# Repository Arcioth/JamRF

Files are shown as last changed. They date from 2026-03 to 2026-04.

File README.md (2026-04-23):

<p align="center">
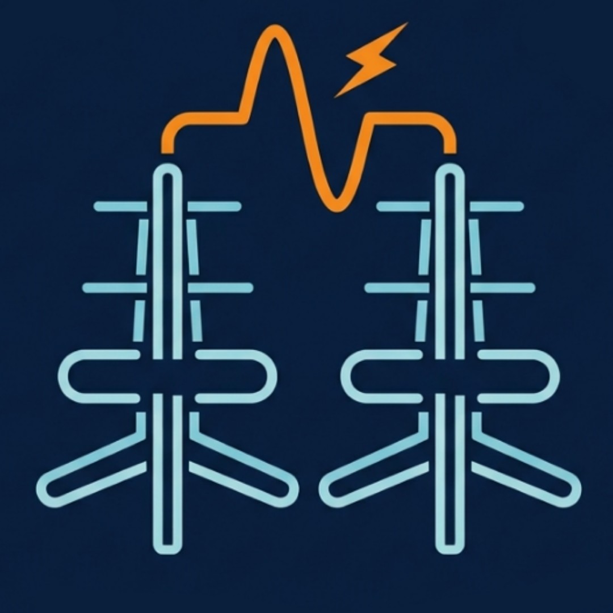
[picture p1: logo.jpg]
jamRF Logo
  
</p>

<h1 align="center">jamRF</h1>

<p align="center">
  <strong>Chaos-modulated RF jammer hardware platform</strong>
</p>

<p align="center">
  
  
  
  
</p>

---

> **This project is NOT affiliated with or related to [TIIUAE's JamRF](https://github.com/tiiuae/jamrf).** TIIUAE's JamRF is an SDR-based RF testing framework built on software-defined radio platforms. This project is an entirely independent custom PCB hardware design for a chaos-modulated RF jammer — purpose-built analog/RF hardware with no SDR components, no shared codebase, and a fundamentally different architecture.

---
<p align="center">
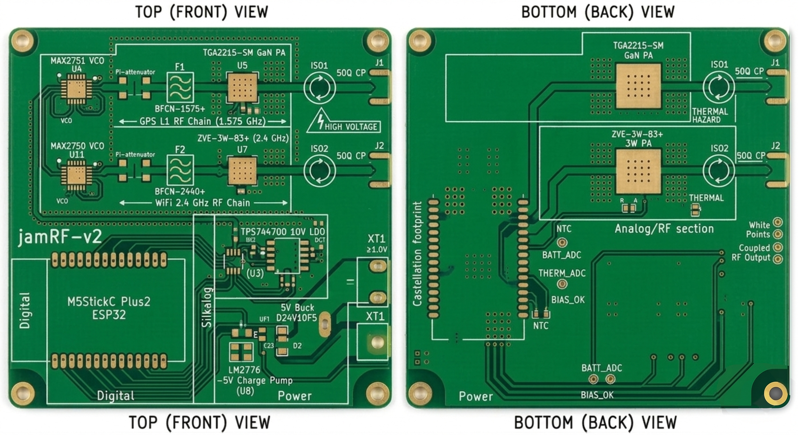
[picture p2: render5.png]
KiCad Render visualizer (click for schematic)
  
  KiCad Render visualizer [click for schematic](https://github.com/Arcioth/JamRF/blob/main/output.pdf)
</p>
---

> **Legal Notice:** This design is published for educational and research purposes only. Intentional RF interference is illegal in most jurisdictions. The user is solely responsible for ensuring compliance with all applicable local, national, and international regulations. The author assumes no liability for misuse.

## Architecture

JamRF v2 uses a hierarchical schematic design inspired by the [HackRF One](https://github.com/greatscottgadgets/hackrf) baseband/frontend separation pattern.

```
                         +--[ Frontend GPS ]---> SMA (1.575 GHz Yagi)
                         |   MAX2751 VCO -> Pi-Atten -> BPF -> TGA2215-SM GaN PA -> Isolator
                         |
[ Baseband ] --- DAC --->+
  M5StickC Plus2         |
  (ESP32-PICO-V3-02)     +--[ Frontend WiFi ]--> SMA (2.4 GHz Yagi)
       |                     MAX2750 VCO -> Pi-Atten -> BPF -> ZVE-3W-83+ PA -> Isolator
       |
  [ Control ]            [ Power ]
  LM393 comparator       4S LiPo (14.8V)
  NTC thermal monitor    D24V10F5 buck (5V)
  GaN bias sequencing    TPS7A4700 LDO (5V analog)
                         LM2776 charge pump (-5V)
                         P-FET switched PA rails
```

### Signal Generation

Both RF chains use chaos-modulated VCOs. The ESP32's DAC outputs (G25, G26) drive the TUNE pins of the MAX2751 and MAX2750 VCOs, sweeping them across their respective bands. The chaotic modulation signal spreads spectral energy across the target bandwidth.

### Power System

- **Input:** 14.8V 4S LiPo (XT60 connector, min 80C discharge)
- **5V digital rail:** Pololu D24V10F5 fixed buck converter
- **5V analog rail:** TPS7A4700 ultra-low-noise LDO (ANY-OUT: 1.4+3.2+0.4V) for VCO supply
- **-5V bias rail:** LM2776 inverting charge pump for GaN PA gate bias
- **15V WiFi PA rail:** Pololu U3V70F15 buck-boost regulator (limits 4S LiPo to safe 15V for ZVE-3W-83+)
- **PA power:** P-FET high-side switches (SQJ407EP) with 2N7002 level shifters
- **Inrush protection:** RC snubber (10R + 1uF) across WiFi PA switch, 33uF hot-plug damping cap

### GaN PA Safety

The TGA2215-SM is a depletion-mode GaN device requiring -5V gate bias *before* drain voltage to prevent destructive Idss runaway:

1. **Enable:** BIAS_EN HIGH -> LM2776 generates -5V -> LM393 comparator confirms bias present (BIAS_OK HIGH) -> Q1 turns on drain power
2. **Disable:** Drain power OFF first -> 15ms POSCAP bleed delay -> charge pump OFF

### Firmware

The ESP32 runs `main.py` (MicroPython) — full operational firmware with chaos modulation engine, ST7789 display driver, mode selection (OFF/GPS/WIFI/DUAL), and safety monitoring. A minimal `failsafe.py` is also provided for thermal-only protection.

Monitoring includes:
- **Temperature:** NTC thermistor on heatsink, shutdown at 85C, recovery at 80C
- **Battery voltage:** Resistive divider (100k/22k), cutoff at 13.0V, recovery at 13.5V
- **Sensor health:** 5 consecutive fault readings trigger permanent lockout
- **Watchdog:** 10-second hardware WDT resets system if firmware hangs

## PCB Specifications

| Parameter | Value |
|---|---|
| Layers | 4 (F.Cu / GND / PWR / B.Cu) |
| Material | Isola FR408HR, 0.062", 1oz Cu (Er=3.65, tan δ=0.0095) |
| Impedance | 50-ohm controlled (0.40mm microstrip over 0.2mm prepreg) |
| Finish | ENIG |
| Board size | 120 x 90 mm |

### Net Classes

| Class | Trace | Clearance | Usage |
|---|---|---|---|
| Default | 0.254mm | 0.2mm | General signals |
| RF_50ohm | 0.40mm | 0.3mm | RF signal paths |
| Power | 1.0mm | 0.3mm | Power distribution |
| HighPower | 2.54mm | 0.5mm | PA supply rails |

## Bill of Materials

See [`hardware/BOM.csv`](hardware/BOM.csv) for the full component list (~60 parts). Key components:

| Ref | Part | Function |
|-----|---|---|
| U1 | M5StickC Plus 2 | ESP32 controller module |
| U4 | MAX2751 | GPS L1 VCO (1.575 GHz) |
| U5 | MAX2750 | WiFi VCO (2.4 GHz) |
| U6 | TGA2215-SM | GaN RF power amplifier (GPS) |
| U7 | ZVE-3W-83+ | 3W RF amplifier module (WiFi) |
| F1 | BFCN-1575+ | GPS L1 bandpass filter |
| F2 | BFCN-2440+ | WiFi bandpass filter |
| ISO1 | B1015 | GPS RF isolator |
| ISO2 | B2425 | WiFi RF isolator |

## Building

### Requirements

- [KiCad 9.0](https://www.kicad.org/) or later
- [MicroPython](https://micropython.org/) for ESP32 firmware

### Opening the Project

```bash
kicad hardware/jamrf-v2.kicad_pro
```

The project uses a custom symbol library (`jamrf-v2.kicad_sym`) included in the `hardware/` directory. Standard KiCad footprint libraries are referenced via `KICAD7_FOOTPRINT_DIR`.

### Flashing Firmware

```bash
# Connect M5StickC Plus 2 via USB
# Full operational firmware:
mpremote cp firmware/main.py :main.py
# Or thermal failsafe only:
mpremote cp firmware/failsafe.py :main.py
```

## Known Limitations

- Component references are unannotated (`U?`, `R?`) — run KiCad Annotate Schematic before generating production files

## Acknowledgments

This design draws architectural inspiration from the [HackRF One](https://github.com/greatscottgadgets/hackrf) by Great Scott Gadgets, licensed under CERN-OHL-P v2. JamRF v2 is an independent design using different components and signal chains.

## License

This project is licensed under the [CERN Open Hardware Licence Version 2 - Permissive](LICENSE) (CERN-OHL-P v2).

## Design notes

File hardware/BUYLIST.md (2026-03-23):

# JamRF v2 — Component Buy List

> **Supplier priority:** Turkish domestic suppliers (Direnc.net, Robotistan.com) first,
> then European distributors that ship to Türkiye (Mouser TR, Farnell TR, TME, RS Components TR).
> For specialty RF components (Mini-Circuits, Qorvo) the manufacturers' own stores or Mouser/DigiKey are used.

---

## Legend

| Symbol | Meaning |
|---|---|
| 🇹🇷 | Turkish domestic supplier (ships from within Turkey) |
| 🌍 | European distributor with Turkey shipping |
| 🌐 | Global supplier (manufacturer / international distributor) |

---

## Modules & Development Boards

### U1 — M5StickC Plus2 (ESP32-PICO-V3-02 controller)
| # | Supplier | Link | Notes |
|---|---|---|---|
| 1 | 🌐 M5Stack Official Store | [shop.m5stack.com — M5StickC PLUS2 ($19.95)](https://shop.m5stack.com/products/m5stickc-plus2-esp32-mini-iot-development-kit) | Ships worldwide from China |
| 2 | 🇹🇷 Robotistan.com | [robotistan.com — search "M5StickC Plus2"](https://www.robotistan.com/m5-stickc-plus2) | Check current stock; largest TR maker store |

### U2 — Pololu D24V10F5 (5V 1A Fixed Buck Converter Module)
| # | Supplier | Link | Notes |
|---|---|---|---|
| 1 | 🌐 Pololu Official | [pololu.com/product/2831](https://www.pololu.com/product/2831) | Ships internationally to Turkey |
| 2 | 🌍 TME (Transfer Multisort Elektronik) | [tme.eu — POLOLU-2831](https://www.tme.eu/en/details/pololu-2831/converter-modules/pololu/5v-1a-step-down-d24v10f5/) | EU warehouse, ships to Turkey |

### U_BOOST — Pololu U3V70F15 (15V Boost Regulator for WiFi PA)
| # | Supplier | Link | Notes |
|---|---|---|---|
| 1 | 🌐 Pololu Official | [pololu.com/product/2896](https://www.pololu.com/product/2896) | Ships internationally to Turkey |
| 2 | 🌍 TME | [tme.eu — search "U3V70F15"](https://www.tme.eu/en/search/?search=U3V70F15) | Check stock; TME carries Pololu modules |

---

## Power Connectors

### J1 — XT60 Battery Connector (4S LiPo, min 80C rating)
| # | Supplier | Link | Notes |
|---|---|---|---|
| 1 | 🇹🇷 Direnc.net | [direnc.net — XT60 60A LiPo Connector](https://www.direnc.net/xt60-plug-60a-li-po-konnektor) | Male+Female pair, ships from Turkey |
| 2 | 🇹🇷 Robotistan.com | [robotistan.com — XT60 Male Connector](https://www.robotistan.com/xt60-battery-male-connector) | Also see: [Female](https://www.robotistan.com/xt60-battery-female-connector-1) |

---

## RF SMA Connectors

### J2, J3 — SMA Edge-Mount Connector (50 Ω, PCB edge launch)
| # | Supplier | Link | Notes |
|---|---|---|---|
| 1 | 🇹🇷 Direnc.net | [direnc.net — SMA Female PCB Mount 50R 18GHz](https://www.direnc.net/sma-disi-pcb-dayanagi-konnektor-50r-18ghz-en) | SMD PCB mount 50Ω |
| 2 | 🌍 Mouser TR | [mouser.com.tr — SMA 50Ω Edge Launch](https://www.mouser.com.tr/c/connectors/rf-interconnects/rf-connectors-coaxial-connectors/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) | Filter: Edge Launch, SMA, 50Ω |

---

## Protection & TVS

### D1 — SMAJ5.0A Unidirectional TVS Diode (5V, SMA package)
| # | Supplier | Link | Notes |
|---|---|---|---|
| 1 | 🇹🇷 Direnc.net | [direnc.net — SMAJ5.0A-E3/61T SMD Transil Diode](https://www.direnc.net/smaj50a-e3-61t-smd-transil-diyot-en) | Vishay brand, 400W, in stock (99k+ units) |
| 2 | 🌍 Mouser TR | [mouser.com.tr — search SMAJ5.0A](https://www.mouser.com.tr/Search/Refine?Keyword=SMAJ5.0A) | Littelfuse / Vishay variants available |

---

## Power Management ICs

### U3 — TPS7A4700RGWT (Ultra-Low Noise LDO, VQFN-20)
| # | Supplier | Link | Notes |
|---|---|---|---|
| 1 | 🌍 Mouser TR | [mouser.com.tr — TPS7A4700RGWT](https://www.mouser.com.tr/ProductDetail/Texas-Instruments/TPS7A4700RGWT) | Search: TPS7A4700RGWT; ships to Turkey |
| 2 | 🌐 DigiKey | [digikey.com — TPS7A4700RGWT](https://www.digikey.com/en/products/detail/texas-instruments/TPS7A4700RGWT/3516858) | Cut tape available, ships same day |

### U8 — LM2776 (Inverting Charge Pump, −5V, SOT-23-6)
| # | Supplier | Link | Notes |
|---|---|---|---|
| 1 | 🌍 Mouser TR | [mouser.com.tr — LM2776 TI page](https://www.mouser.com.tr/new/texas-instruments/ti-lm2776-converter/) | Texas Instruments LM2776; ships to Turkey |
| 2 | 🌐 DigiKey | [digikey.com — search LM2776](https://www.digikey.com/en/products/result?keywords=LM2776) | SOT-23-6 or SC-70-6 variants |

### U9 — LM393 (Dual Comparator, SOIC-8)
| # | Supplier | Link | Notes |
|---|---|---|---|
| 1 | 🇹🇷 Direnc.net | [direnc.net — LM393 SOIC-8 SMD (Onsemi)](https://www.direnc.net/lm393-soic-8-smd-komparator-entegresi-en) | 2,494 units in stock; ~1.41 TL |
| 2 | 🌍 Mouser TR | [mouser.com.tr — search LM393 SOIC-8](https://www.mouser.com.tr/Search/Refine?Keyword=LM393&Ns=Pricing%7C0) | Multiple brands available |

---

## RF Oscillators (VCOs)

### U4 — MAX2751EUA+ (GPS L1 1.575 GHz VCO, SOT-23-6)
| # | Supplier | Link | Notes |
|---|---|---|---|
| 1 | 🌍 Mouser TR | [mouser.com.tr — search MAX2751EUA+](https://www.mouser.com.tr/Search/Refine?Keyword=MAX2751) | Analog Devices (Maxim); verify SOT-23-6 variant |
| 2 | 🌐 DigiKey | [digikey.com — MAX2751](https://www.digikey.com/en/products/base-product/maxim-integrated/175/MAX2751/119046) | Select EUA+ (SOT-23-6) variant from page |

### U5 — MAX2750EUA+ (2.4 GHz ISM VCO, SOT-23-6)
| # | Supplier | Link | Notes |
|---|---|---|---|
| 1 | 🌐 Mouser | [mouser.com — MAX2750EUA+](https://www.mouser.com/ProductDetail/Maxim-Integrated/MAX2750EUA+?qs=GxOUx7aO6nziIWwKBH4Icg%3D%3D) | Same-day shipping available |
| 2 | 🌐 DigiKey | [digikey.com — MAX2750EUA+](https://www.digikey.com/en/products/detail/analog-devices-inc-maxim-integrated/MAX2750EUA/1512311) | ~$9.02/unit; ships same day |

---

## RF Bandpass Filters

### F1 — BFCN-1575+ (GPS L1 1.575 GHz LTCC BPF, FV1206)
| # | Supplier | Link | Notes |
|---|---|---|---|
| 1 | 🌐 Mini-Circuits Official | [minicircuits.com — BFCN-1575+](https://www.minicircuits.com/WebStore/dashboard.html?model=BFCN-1575) | Direct from manufacturer; global shipping |
| 2 | 🌍 Mouser TR | [mouser.com.tr — search BFCN-1575+](https://www.mouser.com.tr/Search/Refine?Keyword=BFCN-1575%2B) | Mini-Circuits authorized distributor |

### F2 — BFCN-2440+ (2.44 GHz LTCC BPF, FV1206)
| # | Supplier | Link | Notes |
|---|---|---|---|
| 1 | 🌐 Mini-Circuits Official | [minicircuits.com — BFCN-2440+](https://www.minicircuits.com/WebStore/dashboard.html?model=BFCN-2440+) | Direct from manufacturer |
| 2 | 🌍 Mouser TR | [mouser.com.tr — search BFCN-2440+](https://www.mouser.com.tr/Search/Refine?Keyword=BFCN-2440%2B) | Check Mini-Circuits stock at Mouser |

---

## RF Amplifiers

### U6 — TGA2215-SM (Qorvo GaN PA, GPS L1, QFN-32)
> ⚠️ **Controlled component** — requires end-user statement. GaN on SiC depletion-mode device.
> This part may need to be ordered directly from Qorvo or via an authorized distributor with export documentation.

| # | Supplier | Link | Notes |
|---|---|---|---|
| 1 | 🌐 Mouser | [mouser.com — search TGA2215-SM](https://www.mouser.com/Search/Refine?Keyword=TGA2215-SM) | Qorvo authorized distributor |
| 2 | 🌐 DigiKey | [digikey.com — search TGA2215-SM](https://www.digikey.com/en/products/result?keywords=TGA2215-SM) | Contact Qorvo if not listed |

### U7 — ZVE-3W-83+ (Mini-Circuits WiFi PA, 2–8 GHz, 3W connectorized)
| # | Supplier | Link | Notes |
|---|---|---|---|
| 1 | 🌐 Mini-Circuits Official | [minicircuits.com — ZVE-3W-83+](https://www.minicircuits.com/WebStore/dashboard.html?model=ZVE-3W-83+) | Connectorized SMA module, direct buy |
| 2 | 🌐 Mouser | [mouser.com — ZVE-3W-83+](https://www.mouser.com/ProductDetail/Mini-Circuits/ZVE-3W-83+?qs=IPgv5n7u5QY6glWktaGMIw%3D%3D) | Same-day shipping |
| 3 | 🌐 DigiKey | [digikey.com — ZVE-3W-83+](https://www.digikey.com/en/products/detail/mini-circuits/ZVE-3W-83/20526845) | Ships today |

---

## RF Isolators

### ISO1 — Mini-Circuits B1015 (Drop-In Isolator, ~1.575 GHz)
| # | Supplier | Link | Notes |
|---|---|---|---|
| 1 | 🌐 Mini-Circuits Official | [minicircuits.com — model search B1015](https://www.minicircuits.com/WebStore/modelSearch.html?model=B1015&search=1) | Contact sales if not listed online |
| 2 | 🌍 Mouser TR | [mouser.com.tr — Mini-Circuits RF Isolators](https://www.mouser.com.tr/c/rf-wireless/rf-integrated-circuits/rf-isolators/?m=Mini-Circuits) | Browse or search "B1015" |

### ISO2 — Mini-Circuits B2425 (Drop-In Isolator, 2.4 GHz)
| # | Supplier | Link | Notes |
|---|---|---|---|
| 1 | 🌐 Mini-Circuits Official | [minicircuits.com — model search B2425](https://www.minicircuits.com/WebStore/modelSearch.html?model=B2425&search=1) | Contact sales if not listed online |
| 2 | 🌍 Mouser TR | [mouser.com.tr — Mini-Circuits RF Isolators](https://www.mouser.com.tr/c/rf-wireless/rf-integrated-circuits/rf-isolators/?m=Mini-Circuits) | Browse or search "B2425" |

---

## MOSFETs

### Q1, Q2 — SQJ407EP-T1_GE3 (P-Channel 60V 10A, PowerPAK SO-8)
| # | Supplier | Link | Notes |
|---|---|---|---|
| 1 | 🌍 Mouser TR | [mouser.com.tr — search SQJ407EP](https://www.mouser.com.tr/Search/Refine?Keyword=SQJ407EP) | Vishay Siliconix; ships to Turkey |
| 2 | 🌐 DigiKey | [digikey.com — search SQJ407EP](https://www.digikey.com/en/products/result?keywords=SQJ407EP) | ~$1.55/unit |

### Q_N1, Q3 — 2N7002 (N-Channel 60V 300mA, SOT-23)
| # | Supplier | Link | Notes |
|---|---|---|---|
| 1 | 🇹🇷 Direnc.net | [direnc.net — 2N7002 SOT-23 60V 250mA](https://www.direnc.net/2n7002-n-kanal-mosfet-sot-23-smd-60v-250ma) | Panjit brand; 99,999 units in stock |
| 2 | 🌐 DigiKey | [digikey.com — 2N7002 (Onsemi)](https://www.digikey.com/en/products/detail/onsemi/2N7002/244345) | Ships same day |

---

## Capacitors

> All Murata GRM series MLCC capacitors can be found at **TME** and **Mouser TR**.
> Search by exact part number (e.g. `GRM21BR61E106KA73L`) on these sites.

### Bulk Capacitors (by part number)

| Ref | Part Number | Value | Package | TME Link | Mouser TR |
|-----|---|---|---|---|---|
| C_IN1, C_LDO_IN, C_GaN_BULK | GRM21BR61E106KA73L | 10µF 25V X5R | 0805 | [tme.eu search](https://www.tme.eu/en/search/?search=GRM21BR61E106KA73L) | [mouser.com.tr search](https://www.mouser.com.tr/Search/Refine?Keyword=GRM21BR61E106KA73L) |
| C_IN2, C_GaN_HF | GRM188R71E104KA01D | 100nF 25V X7R | 0603 | [tme.eu search](https://www.tme.eu/en/search/?search=GRM188R71E104KA01D) | [mouser.com.tr search](https://www.mouser.com.tr/Search/Refine?Keyword=GRM188R71E104KA01D) |
| C_LDO_OUT | GRM21BR61C106KE15L | 10µF 16V X5R | 0805 | [tme.eu search](https://www.tme.eu/en/search/?search=GRM21BR61C106KE15L) | [mouser.com.tr search](https://www.mouser.com.tr/Search/Refine?Keyword=GRM21BR61C106KE15L) |
| C_NR, C_FLY | GRM155R71C105KA12D | 1µF 16V X7R | 0402 | [tme.eu search](https://www.tme.eu/en/search/?search=GRM155R71C105KA12D) | [mouser.com.tr search](https://www.mouser.com.tr/Search/Refine?Keyword=GRM155R71C105KA12D) |
| C_VCO1, C_VCO2 | GRM155R71C104KA88D | 100nF 16V X7R | 0402 | [tme.eu search](https://www.tme.eu/en/search/?search=GRM155R71C104KA88D) | [mouser.com.tr search](https://www.mouser.com.tr/Search/Refine?Keyword=GRM155R71C104KA88D) |
| C_SNUB | GRM188R71E105KA12D | 1µF 25V X7R | 0603 | [tme.eu search](https://www.tme.eu/en/search/?search=GRM188R71E105KA12D) | [mouser.com.tr search](https://www.mouser.com.tr/Search/Refine?Keyword=GRM188R71E105KA12D) |
| C_BULK_IN | GRM32ER71H336KE15L | 33µF 50V X7R | 1210 | [tme.eu search](https://www.tme.eu/en/search/?search=GRM32ER71H336KE15L) | [mouser.com.tr search](https://www.mouser.com.tr/Search/Refine?Keyword=GRM32ER71H336KE15L) |
| C_CP_OUT | GRM21BR61A106KE19L | 10µF 10V X5R | 0805 | [tme.eu search](https://www.tme.eu/en/search/?search=GRM21BR61A106KE19L) | [mouser.com.tr search](https://www.mouser.com.tr/Search/Refine?Keyword=GRM21BR61A106KE19L) |
| C_CP_IN | GRM155R71A105KE01D | 1µF 10V X5R | 0402 | [tme.eu search](https://www.tme.eu/en/search/?search=GRM155R71A105KE01D) | [mouser.com.tr search](https://www.mouser.com.tr/Search/Refine?Keyword=GRM155R71A105KE01D) |
| C_COMP | GRM155R71A104KA01D | 100nF 10V X7R | 0402 | [tme.eu search](https://www.tme.eu/en/search/?search=GRM155R71A104KA01D) | [mouser.com.tr search](https://www.mouser.com.tr/Search/Refine?Keyword=GRM155R71A104KA01D) |

### C1–C4 — Panasonic 25TQC100MYF (100µF 25V POSCAP-D)
| # | Supplier | Link | Notes |
|---|---|---|---|
| 1 | 🌍 Mouser TR | [mouser.com.tr — Panasonic TQC POSCAP series](https://eu.mouser.com/new/panasonic/panasonic-tqc-conductive-poscap/) | Search "25TQC100MYF" or "100uF 25V TQC" |
| 2 | 🌐 DigiKey | [digikey.com — search 25TQC100MYF](https://www.digikey.com/en/products/result?keywords=25TQC100MYF) | Also check 20TQC100MYF (20V variant as fallback) |

---

## Resistors

> All Vishay CRCW0603 series 1% resistors. Best ordered from Mouser TR or TME.
> TME URL format: `https://www.tme.eu/en/search/?search=<PART_NUMBER>`

### Vishay CRCW0603 Resistor Summary

| Ref(s) | Part Number | Value | Supplier 1 (Mouser TR) | Supplier 2 (TME) |
|---|---|---|---|---|
| R1, R3, R4, R6 | CRCW0603292RFKTA | 292Ω 1% | [mouser.com.tr — CRCW0603292RFKTA](https://www.mouser.com.tr/Search/Refine?Keyword=CRCW0603292RFKTA) | [tme.eu — CRCW0603292RFKTA](https://www.tme.eu/en/search/?search=CRCW0603292RFKTA) |
| R2, R5 | CRCW060318R0FKTA | 18Ω 1% | [mouser.com.tr — CRCW060318R0FKTA](https://www.mouser.com.tr/Search/Refine?Keyword=CRCW060318R0FKTA) | [tme.eu — CRCW060318R0FKTA](https://www.tme.eu/en/search/?search=CRCW060318R0FKTA) |
| R_SNUB | CRCW060310R0FKTA | 10Ω 1% | [mouser.com.tr — CRCW060310R0FKTA](https://www.mouser.com.tr/Search/Refine?Keyword=CRCW060310R0FKTA) | [tme.eu — CRCW060310R0FKTA](https://www.tme.eu/en/search/?search=CRCW060310R0FKTA) |
| R_PU, R_TH | CRCW060310K0FKTA | 10kΩ 1% | [mouser.com.tr — CRCW060310K0FKTA](https://www.mouser.com.tr/Search/Refine?Keyword=CRCW060310K0FKTA) | [tme.eu — CRCW060310K0FKTA](https://www.tme.eu/en/search/?search=CRCW060310K0FKTA) |
| R_G1, R_Q2_PU, R_DIV1, R_REF1, R_BATT1 | CRCW0603100KFKTA | 100kΩ 1% | [mouser.com.tr — CRCW0603100KFKTA](https://www.mouser.com.tr/Search/Refine?Keyword=CRCW0603100KFKTA) | [tme.eu — CRCW0603100KFKTA](https://www.tme.eu/en/search/?search=CRCW0603100KFKTA) |
| R_DIV2 | CRCW0603270KFKTA | 270kΩ 1% | [mouser.com.tr — CRCW0603270KFKTA](https://www.mouser.com.tr/Search/Refine?Keyword=CRCW0603270KFKTA) | [tme.eu — CRCW0603270KFKTA](https://www.tme.eu/en/search/?search=CRCW0603270KFKTA) |
| R_REF2 | CRCW060382K0FKTA | 82kΩ 1% | [mouser.com.tr — CRCW060382K0FKTA](https://www.mouser.com.tr/Search/Refine?Keyword=CRCW060382K0FKTA) | [tme.eu — CRCW060382K0FKTA](https://www.tme.eu/en/search/?search=CRCW060382K0FKTA) |
| R_BATT2 | CRCW060322K0FKTA | 22kΩ 1% | [mouser.com.tr — CRCW060322K0FKTA](https://www.mouser.com.tr/Search/Refine?Keyword=CRCW060322K0FKTA) | [tme.eu — CRCW060322K0FKTA](https://www.tme.eu/en/search/?search=CRCW060322K0FKTA) |

> **Tip:** If exact Vishay CRCW part numbers are out of stock, any 0603 1% thick-film 100mW resistor in the correct value is a valid substitute (e.g., Yageo RC0603FR series, Panasonic ERA series).

---

## Thermistor

### TH1 — NTCS0805E3103FMT (Vishay 10kΩ NTC, 0805, B=3570K)
| # | Supplier | Link | Notes |
|---|---|---|---|
| 1 | 🌐 DigiKey | [digikey.com — NTCS0805E3103FMT](https://www.digikey.com/en/products/detail/vishay-beyschlag-draloric-bc-components/NTCS0805E3103FMT/2237367) | Ships today; ±1% tolerance |
| 2 | 🌍 TME | [tme.eu — NTCS0805E3103FMT](https://www.tme.eu/en/details/ntcs0805e3103fmt/smd-measurement-ntc-thermistors/vishay/) | EU warehouse, ships to Turkey |

---

## RF Shield Cans

### SH1, SH2 — Würth Elektronik 36103305 (SMD Shield Can)
| # | Supplier | Link | Notes |
|---|---|---|---|
| 1 | 🌍 Mouser TR | [mouser.com.tr — Wurth 36103305](https://www.mouser.com/ProductDetail/Wurth-Elektronik/36103305?qs=c50eh9DPO4O7TwWEHqYVOw%3D%3D) | Frame + cover; ~$3.91 per set |
| 2 | 🌐 DigiKey | [digikey.com — search 36103305](https://www.digikey.com/en/products/result?keywords=36103305) | ~$4.34; also see 36103305S (frame only) |

---

## Purchasing Tips

### For Turkish buyers
1. **Direnc.net** and **Robotistan.com** cover common passives, connectors, and discrete transistors at low cost with fast domestic shipping.
2. **Mouser TR (`mouser.com.tr`)** is fully stocked and ships from a local Turkish warehouse — best for ICs and specialty passives at volume.
3. **TME (`tme.eu`)** is a Polish distributor but ships to Turkey via DHL/UPS; excellent for Murata/Vishay passives and Pololu modules.
4. **Farnell TR (`tr.farnell.com`)** and **RS Components TR (`tr.rs-online.com`)** are also authorized distributors with Turkish offices.

### Hard-to-find components
| Component | Notes |
|---|---|
| **TGA2215-SM** (Qorvo GaN PA) | Niche RF part; check Mouser/DigiKey. If unavailable, contact [Qorvo sales](https://www.qorvo.com/contact) directly. ECCN classification may require export documentation. |
| **B1015 / B2425** (Mini-Circuits Drop-In Isolators) | Legacy drop-in format; contact [Mini-Circuits sales](https://www.minicircuits.com/contact/) if not listed on web store. |
| **MAX2751 / MAX2750** | Older Maxim VCOs; check Mouser/DigiKey stock. May need to request from Analog Devices (ADI) directly. |

---

*Last updated: 2026-03-23*

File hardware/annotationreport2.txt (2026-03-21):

Annotated R as R17.
Annotated R as R2.
Annotated R as R3.
Annotated R as R4.
Annotated R as R5.
Annotated R as R6.
Annotated R as R7.
Annotated R as R8.
Annotated R as R9.
Annotated R as R10.
Annotated R as R11.
Annotated R as R12.
Annotated R as R13.
Annotated R as R14.
Annotated R as R15.
Annotated R as R16.
Annotated R as R1.
Annotated 36103305 as SH1.
Annotated 36103305 as SH2.
Annotated 10k NTC as TH1.
Annotated M5StickC_Plus2 as U1.
Annotated MAX2751 as U2.
Annotated TGA2215-SM as U3.
Annotated MAX2750 as U4.
Annotated ZVE-3W-83+ as U5.
Annotated D24V10F5 as U6.
Annotated TPS7A4700 as U7.
Annotated U3V70F15 as U8.
Annotated LM2776 as U9.
Annotated LM393 as U10.
Annotation complete.
Annotated C as C17.
Annotated C as C2.
Annotated C as C3.
Annotated C as C4.
Annotated C as C5.
Annotated C as C6.
Annotated C as C7.
Annotated C as C8.
Annotated C as C9.
Annotated C as C10.
Annotated C as C11.
Annotated C as C12.
Annotated C as C13.
Annotated C as C14.
Annotated C as C15.
Annotated C as C16.
Annotated C as C1.
Annotated C as C18.
Annotated C as C19.
Annotated SMAJ5.0A as D1.
Annotated BFCN-1575+ as F1.
Annotated BFCN-2440+ as F2.
Annotated Ferrite_Isolator as ISO1.
Annotated Ferrite_Isolator as ISO2.
Annotated SMA as J1.
Annotated SMA as J2.
Annotated 14.8V 4S LiPo as J3.
Annotated 2N7002 as Q1.
Annotated 2N7002 as Q2.
Annotated SQJ407EP as Q3.
Annotated SQJ407EP as Q4.
Annotation complete.

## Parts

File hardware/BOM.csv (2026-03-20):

Ref | Qty | Description | Value | Manufacturer | Part Number | Package | Sheet | Notes
J1 | 1 | Battery Connector (4S LiPo) | 14.8V | - | - | XT60 | Power | Min 80C-100C discharge rating
U1 | 1 | Central Controller | ESP32-PICO-V3-02 | M5Stack | M5StickC Plus 2 | Module | Baseband | Runs failsafe.py firmware
U2 | 1 | Fixed Buck Converter | 5.0V 1A | Pololu | D24V10F5 | Module | Power | Fixed output - no pot
D1 | 1 | TVS Diode (Unidirectional) | 5.0V | Littelfuse | SMAJ5.0A | SMA | Power | Overvoltage protection on 5V rail
C_IN1 | 1 | Input Decoupling (Buck) | 10uF 25V | Murata | GRM21BR61E106KA73L | 0805 | Power
C_IN2 | 1 | Input Bypass (Buck) | 100nF 25V | Murata | GRM188R71E104KA01D | 0603 | Power
U3 | 1 | Ultra-Low Noise LDO | 5.0V Out (ANY-OUT: 1.4+3.2+0.4) | Texas Instruments | TPS7A4700 | VQFN-20 | Power | Strips battery ripple for VCOs (MAX2750/MAX2751 VCC max 5.5V)
C_LDO_IN | 1 | LDO Input Capacitor | 10uF 25V | Murata | GRM21BR61E106KA73L | 0805 | Power
C_LDO_OUT | 1 | LDO Output Capacitor | 10uF 16V | Murata | GRM21BR61C106KE15L | 0805 | Power
C_NR | 1 | LDO Noise Reduction Cap | 1uF | Murata | GRM155R71C105KA12D | 0402 | Power | Sets NR/SS soft-start time
U4 | 1 | VCO 1 (GPS L1) | 1.575GHz | Maxim Integrated | MAX2751 | SOT-23-6 | Frontend GPS | Chaos-modulated via TUNE pin
U5 | 1 | VCO 2 (Wi-Fi/ISM) | 2.4GHz | Maxim Integrated | MAX2750 | SOT-23-6 | Frontend WiFi | Chaos-modulated via TUNE pin
C_VCO1 | 1 | VCO1 Bypass Cap | 100nF | Murata | GRM155R71C104KA88D | 0402 | Frontend GPS
C_VCO2 | 1 | VCO2 Bypass Cap | 100nF | Murata | GRM155R71C104KA88D | 0402 | Frontend WiFi
R1 | 1 | Pi-Atten GPS Shunt 1 | 292R 1% | Vishay | CRCW0603292RFKTA | 0603 | Frontend GPS | 3dB pi-attenuator
R2 | 1 | Pi-Atten GPS Series | 18R 1% | Vishay | CRCW060318R0FKTA | 0603 | Frontend GPS | 3dB pi-attenuator
R3 | 1 | Pi-Atten GPS Shunt 2 | 292R 1% | Vishay | CRCW0603292RFKTA | 0603 | Frontend GPS | 3dB pi-attenuator
R4 | 1 | Pi-Atten WiFi Shunt 1 | 292R 1% | Vishay | CRCW0603292RFKTA | 0603 | Frontend WiFi | 3dB pi-attenuator
R5 | 1 | Pi-Atten WiFi Series | 18R 1% | Vishay | CRCW060318R0FKTA | 0603 | Frontend WiFi | 3dB pi-attenuator
R6 | 1 | Pi-Atten WiFi Shunt 2 | 292R 1% | Vishay | CRCW0603292RFKTA | 0603 | Frontend WiFi | 3dB pi-attenuator
F1 | 1 | Bandpass Filter (GPS L1) | 1.575GHz | Mini-Circuits | BFCN-1575+ | FV1206 | Frontend GPS | Strict passband filter
F2 | 1 | Bandpass Filter (Wi-Fi) | 2.44GHz | Mini-Circuits | BFCN-2440+ | FV1206 | Frontend WiFi | Strict passband filter
U6 | 1 | GaN RF Amplifier (GPS) | High Power | Qorvo | TGA2215-SM | QFN-32 | Frontend GPS | Requires -5V gate bias + copper coin thermal relief
U7 | 1 | RF Amplifier (Wi-Fi) | 3W | Mini-Circuits | ZVE-3W-83+ | CP1281 | Frontend WiFi | Connectorized module. Vmax=+16V; 4S LiPo at 16.8V exceeds this - consider boost-buck regulator (see v3 U3V70F15)
R_SNUB | 1 | Snubber Resistor | 10R 1/4W | Vishay | CRCW060310R0FKTA | 0603 | Power | Damps POSCAP LC inrush oscillation on Q2 turn-on
C_SNUB | 1 | Snubber Capacitor | 1uF 25V | Murata | GRM188R71E105KA12D | 0603 | Power | RC snubber across Q2 drain-source
C_BULK_IN | 1 | Hot-Plug Damping Cap | 33uF 50V | Murata | GRM32ER71H336KE15L | 1210 | Power | Absorbs LC ringing on battery connect
C1 | 1 | Bulk Capacitor 1 | 100uF 25V | Panasonic | 25TQC100MYF | POSCAP-D | Power | Low-ESR for WiFi PA
C2 | 1 | Bulk Capacitor 2 | 100uF 25V | Panasonic | 25TQC100MYF | POSCAP-D | Power | Low-ESR for WiFi PA
C3 | 1 | Bulk Capacitor 3 | 100uF 25V | Panasonic | 25TQC100MYF | POSCAP-D | Power | Low-ESR for WiFi PA
C4 | 1 | Bulk Capacitor 4 | 100uF 25V | Panasonic | 25TQC100MYF | POSCAP-D | Power | Low-ESR for WiFi PA
U8 | 1 | Inverting Charge Pump | -5V | Texas Instruments | LM2776 | SOT-23-6 | Power | Generates -5V gate bias for GaN PA
C_FLY | 1 | Flying Capacitor | 1uF 16V | Murata | GRM155R71C105KA12D | 0402 | Power | Charge pump flying cap
C_CP_OUT | 1 | Charge Pump Output Cap | 10uF 10V | Murata | GRM21BR61A106KE19L | 0805 | Power | Charge pump output filter
U9 | 1 | Analog Comparator |  | Texas Instruments | LM393 | SOIC-8 | Control | Monitors -5V bias rail presence
Q1 | 1 | P-Channel MOSFET (GaN PA switch) | 60V 10A | Vishay | SQJ407EP | PowerPAK SO-8 | Power | High-side drain switch for GaN PA
Q2 | 1 | P-Channel MOSFET (WiFi PA switch) | 60V 10A | Vishay | SQJ407EP | PowerPAK SO-8 | Power | High-side switch on +14V8_WIFI
Q_N1 | 1 | N-Channel MOSFET (Q1 level shifter) | 60V 300mA | ON Semi | 2N7002 | SOT-23 | Power | Gate=BIAS_OK Drain=Q1gate Source=GND
Q3 | 1 | N-Channel MOSFET (Q2 level shifter) | 60V 300mA | ON Semi | 2N7002 | SOT-23 | Power | Gate=RELAY_CTRL Drain=Q2gate Source=GND
R_PU | 1 | Comparator Pull-Up | 10k | Vishay | CRCW060310K0FKTA | 0603 | Control | Open-collector pull-up to 3V3
R_G1 | 1 | Q1 Gate Pull-Up | 100k 1% | Vishay | CRCW0603100KFKTA | 0603 | Power | Pulls Q1 gate to +14V8 (OFF)
R_Q2_PU | 1 | Q2 Gate Pull-Up | 100k 1% | Vishay | CRCW0603100KFKTA | 0603 | Power | Pulls Q2 gate to +14V8 (OFF)
R_DIV1 | 1 | Sense Divider High (+3V3 side) | 100k 1% | Vishay | CRCW0603100KFKTA | 0603 | Control | Level-shifting divider
R_DIV2 | 1 | Sense Divider Low (-5V side) | 270k 1% | Vishay | CRCW0603270KFKTA | 0603 | Control | Midpoint = 1.06V when -5V present
R_REF1 | 1 | Reference Divider High | 100k 1% | Vishay | CRCW0603100KFKTA | 0603 | Control | Comparator threshold reference
R_REF2 | 1 | Reference Divider Low | 82k 1% | Vishay | CRCW060382K0FKTA | 0603 | Control | Reference = 3.3V * 82k/182k = 1.49V
R_BATT1 | 1 | Battery Divider High | 100k 1% | Vishay | CRCW0603100KFKTA | 0603 | Baseband | Battery voltage monitor
R_BATT2 | 1 | Battery Divider Low | 22k 1% | Vishay | CRCW060322K0FKTA | 0603 | Baseband | Scales 12-16.8V to 2.16-3.03V for ESP32 ADC
ISO1 | 1 | RF Isolator (GPS 1.575GHz) | Broadband | Mini-Circuits | B1015 | Drop-In | Frontend GPS | Prevents reflected power damage
ISO2 | 1 | RF Isolator (WiFi 2.4GHz) | Broadband | Mini-Circuits | B2425 | Drop-In | Frontend WiFi | Prevents reflected power damage
J2 | 1 | SMA Connector (GPS Antenna) | 50 Ohm | - | - | Edge-Mount SMA | Frontend GPS | To 9.3cm Yagi antenna
J3 | 1 | SMA Connector (WiFi Antenna) | 50 Ohm | - | - | Edge-Mount SMA | Frontend WiFi | To 6.2cm Yagi antenna
TH1 | 1 | NTC Thermistor | 10k | Vishay | NTCS0805E3103FMT | 0805 | Control | Mounted on heatsink
R_TH | 1 | Thermistor Series Resistor | 10k | Vishay | CRCW060310K0FKTA | 0603 | Control | Forms voltage divider with NTC
C_CP_IN | 1 | Charge Pump Input Cap | 1uF 10V | Murata | GRM155R71A105KE01D | 0402 | Power | LM2776 VIN local decoupling (required per datasheet)
C_COMP | 1 | Comparator Bypass Cap | 100nF 10V | Murata | GRM155R71A104KA01D | 0402 | Control | LM393 VCC decoupling
C_GaN_BULK | 1 | GaN PA Drain Decoupling | 10uF 25V | Murata | GRM21BR61E106KA73L | 0805 | Frontend GPS | TGA2215-SM drain rail bulk decoupling
C_GaN_HF | 1 | GaN PA HF Bypass | 100nF 25V | Murata | GRM188R71E104KA01D | 0603 | Frontend GPS | TGA2215-SM drain rail HF bypass
SH1 | 1 | RF Shield Can (DC-DC) |  | Wurth | 36103305 | Shield Can | Power | Isolates switching noise from RF
SH2 | 1 | RF Shield Can (Charge Pump) |  | Wurth | 36103305 | Shield Can | Power | Isolates switching noise from RF

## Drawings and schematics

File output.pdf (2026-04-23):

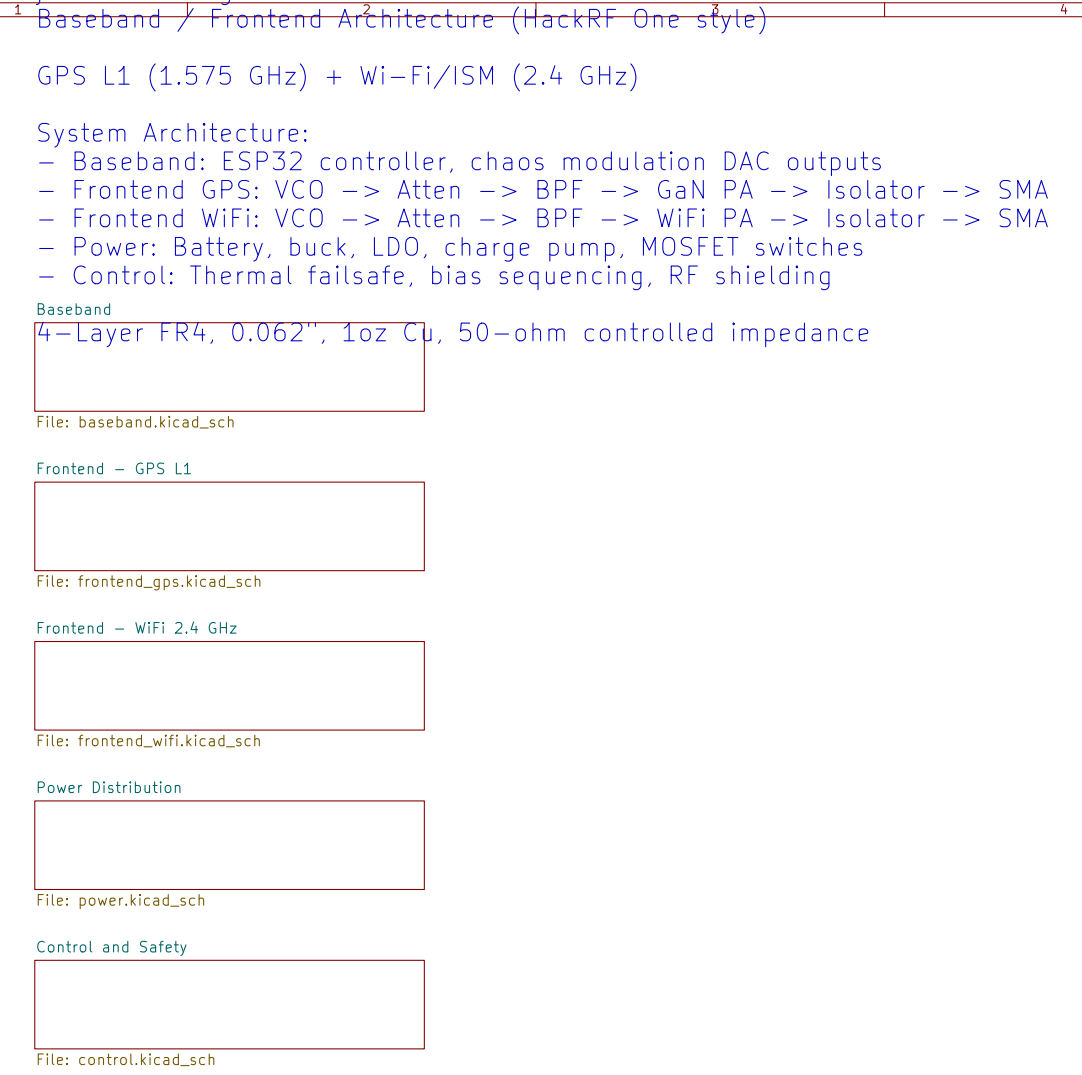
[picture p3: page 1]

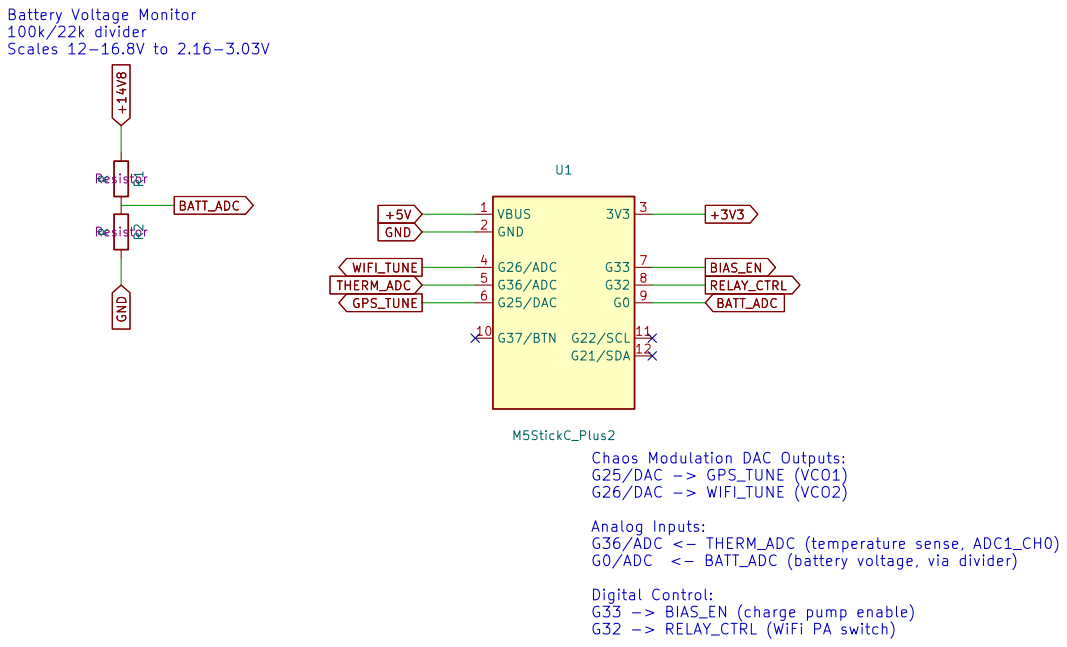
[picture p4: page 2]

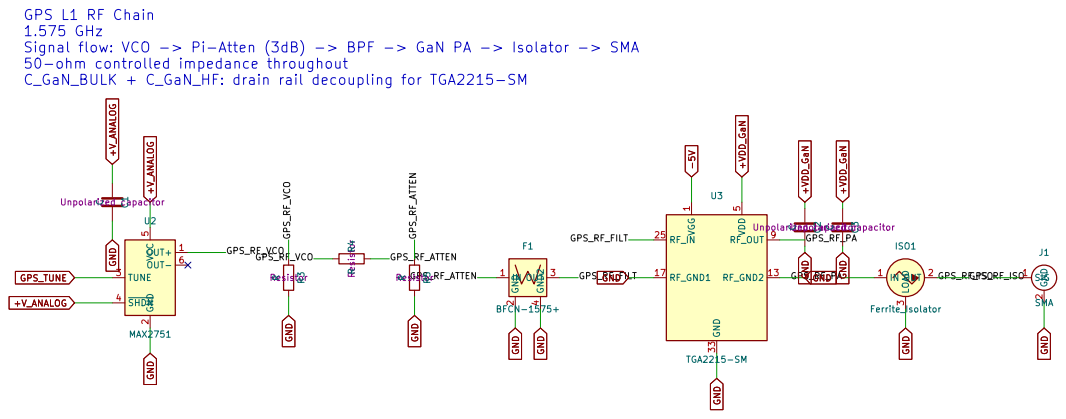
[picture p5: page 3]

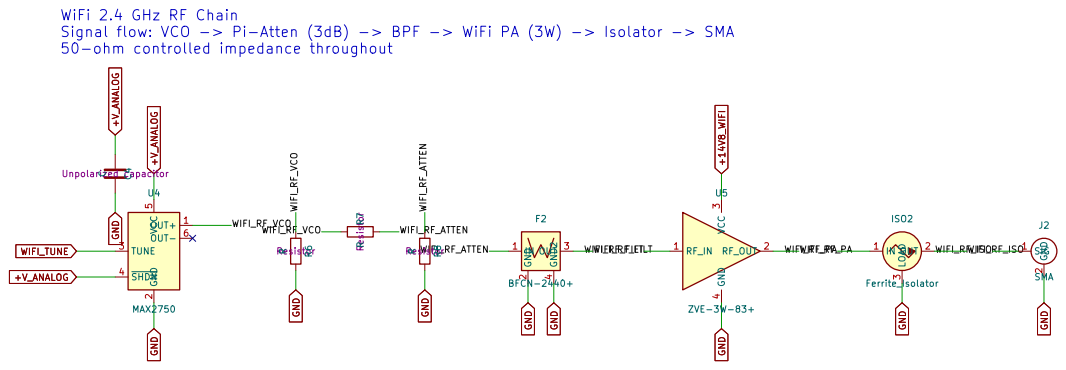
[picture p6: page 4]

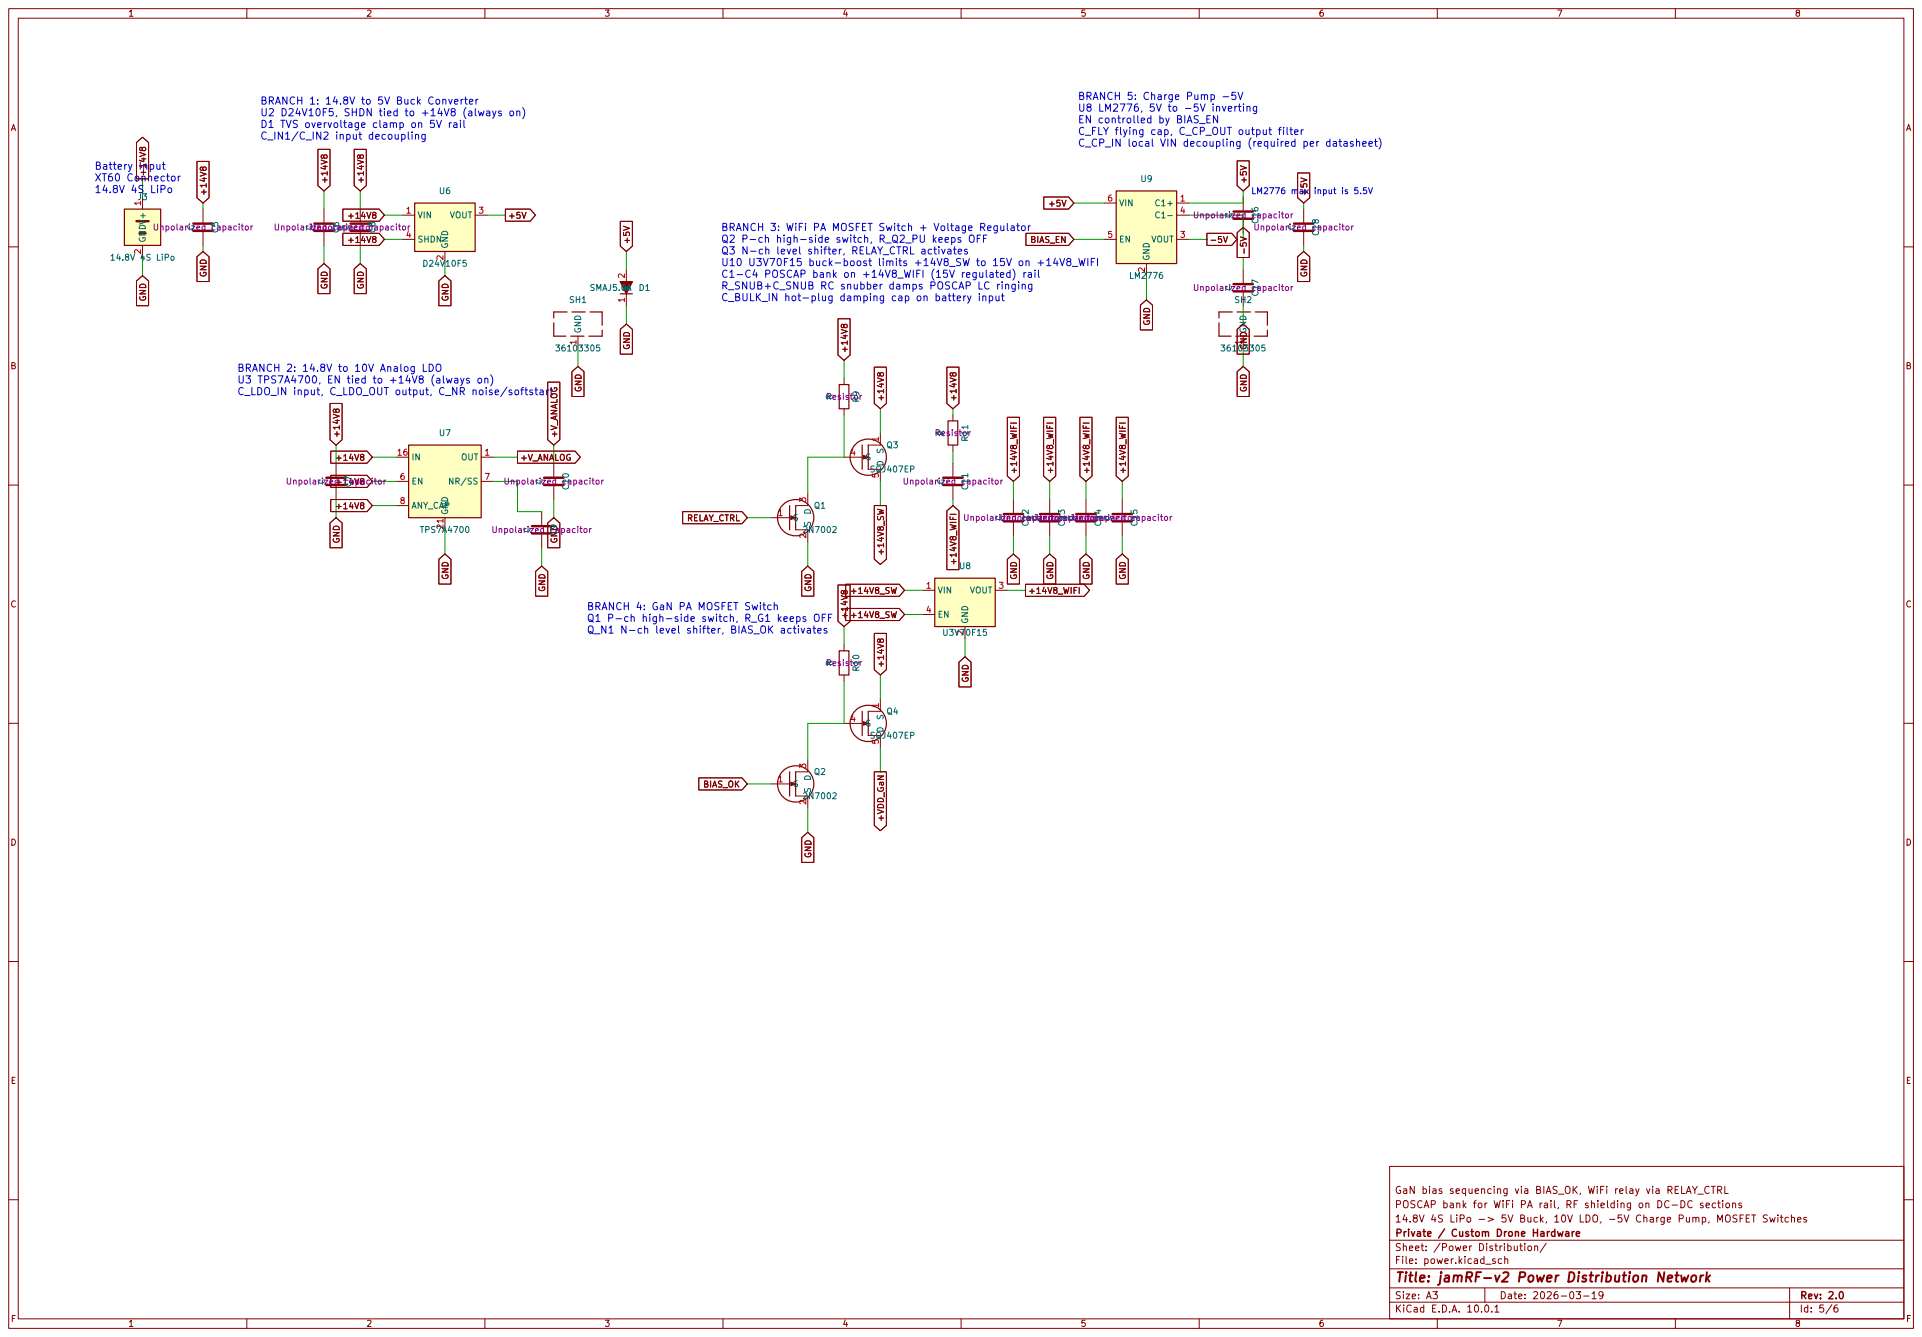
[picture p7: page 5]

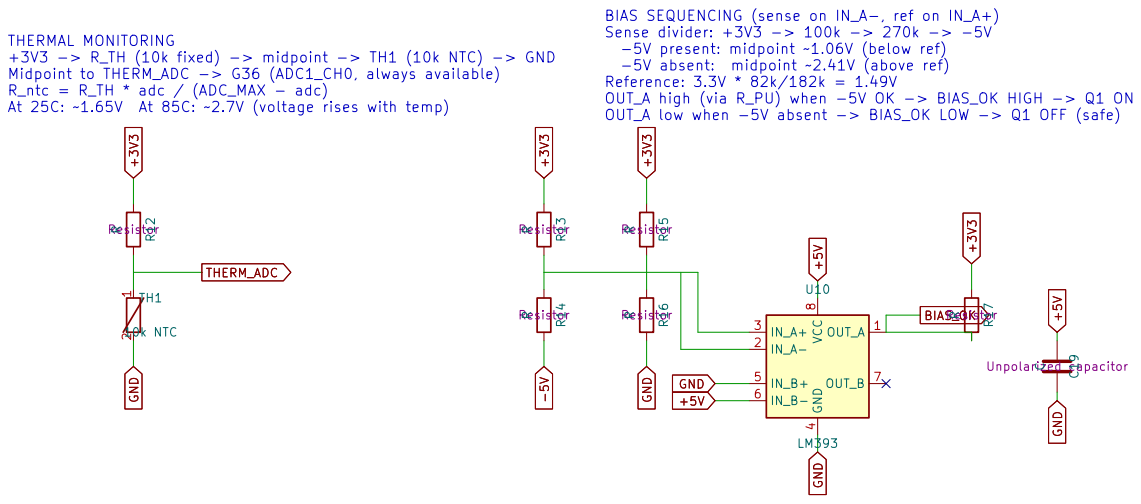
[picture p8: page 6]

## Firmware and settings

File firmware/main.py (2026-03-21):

"""
jamRF-v2 Operational Firmware
=============================
Target: M5StickC Plus 2 (ESP32-PICO-V3-02)
Runtime: MicroPython

Full operational firmware with chaos modulation engine, safety monitoring,
GaN bias sequencing, display UI, and button-driven mode control.

Pin Mapping (matches jamrf-v2 schematic):
  G25/DAC1  GPS_TUNE    — Chaos modulation output to MAX2751 VCO
  G26/DAC2  WIFI_TUNE   — Chaos modulation output to MAX2750 VCO
  G36/ADC   THERM_ADC   — NTC thermistor voltage divider (ADC1_CH0)
  G0/ADC    BATT_ADC    — Battery voltage divider (100k/22k)
  G35/ADC   BIAS_OK     — LM393 comparator output (gate bias confirmation)
  G33       BIAS_EN     — LM2776 charge pump enable (-5V gate bias)
  G32       RELAY_CTRL  — Q3/Q2 WiFi PA MOSFET switch
  G37       BTN_A       — Mode cycle button
  G39       BTN_B       — Parameter adjust button
  G2        BUZZER      — Internal buzzer

Modes (Button A cycles):
  OFF  -> GPS -> WIFI -> DUAL -> OFF

Safety (always active, overrides all modes):
  - Thermal shutdown 85C / recover 80C
  - Battery undervoltage cutoff 13.0V / recover 13.5V
  - GaN bias sequencing: -5V gate bias before drain voltage
  - BIAS_OK readback: LM393 confirms bias present before PA enable
  - Sensor fault lockout after 5 consecutive bad readings
  - 10s watchdog timer
"""

import machine
import time
import math
import struct

# =============================================================================
# PIN CONFIGURATION
# =============================================================================
PIN_GPS_TUNE = 25      # DAC1 output to MAX2751 VCO
PIN_WIFI_TUNE = 26     # DAC2 output to MAX2750 VCO
PIN_THERM_ADC = 36     # NTC thermistor ADC input
PIN_BATT_ADC = 0       # Battery voltage divider ADC input
PIN_BIAS_OK = 35       # LM393 comparator output (input only)
PIN_BIAS_EN = 33       # LM2776 charge pump enable
PIN_RELAY_CTRL = 32    # WiFi PA MOSFET switch
PIN_BTN_A = 37         # Mode button
PIN_BTN_B = 39         # Parameter button
PIN_BUZZER = 2         # Internal buzzer

# =============================================================================
# OPERATING MODES
# =============================================================================
MODE_OFF = 0
MODE_GPS = 1
MODE_WIFI = 2
MODE_DUAL = 3
MODE_NAMES = ["OFF", "GPS", "WIFI", "DUAL"]

# =============================================================================
# SAFETY THRESHOLDS
# =============================================================================
SHUTDOWN_TEMP_C = 85.0
RECOVERY_TEMP_C = 80.0
SENSOR_FAULT_LOW = -20.0
SENSOR_FAULT_HIGH = 150.0
UNDERVOLT_CUTOFF_V = 13.0
UNDERVOLT_RECOVER_V = 13.5
STARTUP_DELAY_S = 3
SAMPLE_INTERVAL_MS = 100    # Safety check rate (10 Hz)
CHAOS_INTERVAL_US = 50      # Chaos update rate (~20 kHz)
ADC_SAMPLES = 16
SEQUENCER_DELAY_MS = 15
MAX_CONSECUTIVE_FAULTS = 5

# =============================================================================
# THERMISTOR PARAMETERS (Vishay NTCS0805E3103FMT)
# =============================================================================
B_COEFFICIENT = 3950
NOMINAL_RESISTANCE = 10000
NOMINAL_TEMP_K = 298.15
SERIES_RESISTOR = 10000
ADC_MAX = 4095
V_REF = 3.3

# =============================================================================
# BATTERY VOLTAGE DIVIDER (R_BATT1=100k / R_BATT2=22k)
# =============================================================================
R_BATT1 = 100000
R_BATT2 = 22000
BATT_DIVIDER_RATIO = (R_BATT1 + R_BATT2) / R_BATT2

# =============================================================================
# VCO TUNING PARAMETERS
#
# MAX2751 (GPS L1, 1.575 GHz): ~200 MHz/V, TUNE 0.4-2.4V
# MAX2750 (WiFi 2.4 GHz):      ~250 MHz/V, TUNE 0.4-2.4V
# ESP32 DAC: 8-bit (0-255), 0-3.3V, 1 step = 12.94 mV
# =============================================================================
GPS_DAC_CENTER = 100    # ~1.29V -> ~1.575 GHz (calibrate on hardware)
GPS_DAC_SWING = 12      # +/-155 mV -> +/-31 MHz spread
WIFI_DAC_CENTER = 116   # ~1.50V -> ~2.4 GHz (calibrate on hardware)
WIFI_DAC_SWING = 16     # +/-207 mV -> +/-52 MHz spread

# =============================================================================
# CHAOS ENGINE PARAMETERS
# =============================================================================
CHAOS_R = 3.9999        # Logistic map parameter (full chaos)
LORENZ_SIGMA = 10.0     # Lorenz attractor parameters
LORENZ_RHO = 28.0
LORENZ_BETA = 8.0 / 3.0
LORENZ_DT = 0.005

# =============================================================================
# DISPLAY — ST7789V2 (M5StickC Plus2: 135x240, SPI)
# =============================================================================
DISP_WIDTH = 135
DISP_HEIGHT = 240
DISP_SCK = 13
DISP_MOSI = 15
DISP_DC = 14
DISP_CS = 5
DISP_RST = 12
DISP_BL = 27

# Colors (RGB565)
BLACK = 0x0000
WHITE = 0xFFFF
RED = 0xF800
GREEN = 0x07E0
BLUE = 0x001F
ORANGE = 0xFD20
YELLOW = 0xFFE0
CYAN = 0x07FF
DARK_BG = 0x1926      # Dark navy matching logo


# =============================================================================
# MINIMAL ST7789 DISPLAY DRIVER
# =============================================================================
class ST7789:
    def __init__(self):
        self.spi = machine.SPI(1, baudrate=40000000, polarity=1, phase=0,
                               sck=machine.Pin(DISP_SCK),
                               mosi=machine.Pin(DISP_MOSI))
        self.dc = machine.Pin(DISP_DC, machine.Pin.OUT)
        self.cs = machine.Pin(DISP_CS, machine.Pin.OUT)
        self.rst = machine.Pin(DISP_RST, machine.Pin.OUT)
        self.bl = machine.Pin(DISP_BL, machine.Pin.OUT)
        self._init_display()

    def _cmd(self, cmd, data=None):
        self.cs.value(0)
        self.dc.value(0)
        self.spi.write(bytes([cmd]))
        if data:
            self.dc.value(1)
            self.spi.write(data)
        self.cs.value(1)

    def _init_display(self):
        self.rst.value(0)
        time.sleep_ms(50)
        self.rst.value(1)
        time.sleep_ms(150)
        self._cmd(0x01)         # SWRESET
        time.sleep_ms(150)
        self._cmd(0x11)         # SLPOUT
        time.sleep_ms(50)
        self._cmd(0x3A, b'\x55')  # COLMOD: 16-bit color
        self._cmd(0x36, b'\x00')  # MADCTL: normal orientation
        self._cmd(0x21)         # INVON (needed for M5StickC)
        self._cmd(0x13)         # NORON
        time.sleep_ms(10)
        self._cmd(0x29)         # DISPON
        self.bl.value(1)

    def _set_window(self, x0, y0, x1, y1):
        # Column offset for 135-wide display centered in 240-wide controller
        xoff = 52
        yoff = 40
        self._cmd(0x2A, struct.pack('>HH', x0 + xoff, x1 + xoff))
        self._cmd(0x2B, struct.pack('>HH', y0 + yoff, y1 + yoff))
        self._cmd(0x2C)

    def fill(self, color):
        self._set_window(0, 0, DISP_WIDTH - 1, DISP_HEIGHT - 1)
        buf = struct.pack('>H', color) * 135
        self.cs.value(0)
        self.dc.value(1)
        for _ in range(240):
            self.spi.write(buf)
        self.cs.value(1)

    def fill_rect(self, x, y, w, h, color):
        self._set_window(x, y, x + w - 1, y + h - 1)
        buf = struct.pack('>H', color) * w
        self.cs.value(0)
        self.dc.value(1)
        for _ in range(h):
            self.spi.write(buf)
        self.cs.value(1)

    def text(self, s, x, y, color=WHITE, scale=1):
        for i, ch in enumerate(s):
            self._draw_char(ch, x + i * 6 * scale, y, color, scale)

    def _draw_char(self, ch, x, y, color, scale):
        idx = ord(ch)
        if idx < 32 or idx > 126:
            idx = 32
        idx -= 32
        for col in range(5):
            line = _FONT[idx * 5 + col]
            for row in range(8):
                if line & (1 << row):
                    if scale == 1:
                        self._pixel(x + col, y + row, color)
                    else:
                        self.fill_rect(x + col * scale, y + row * scale,
                                       scale, scale, color)

    def _pixel(self, x, y, color):
        if 0 <= x < DISP_WIDTH and 0 <= y < DISP_HEIGHT:
            self._set_window(x, y, x, y)
            self.cs.value(0)
            self.dc.value(1)
            self.spi.write(struct.pack('>H', color))
            self.cs.value(1)


# 5x8 font (ASCII 32-126, 5 bytes per character)
_FONT = bytes([
    0x00,0x00,0x00,0x00,0x00, # space
    0x00,0x00,0x5F,0x00,0x00, # !
    0x00,0x07,0x00,0x07,0x00, # "
    0x14,0x7F,0x14,0x7F,0x14, # #
    0x24,0x2A,0x7F,0x2A,0x12, # $
    0x23,0x13,0x08,0x64,0x62, # %
    0x36,0x49,0x56,0x20,0x50, # &
    0x00,0x08,0x07,0x03,0x00, # '
    0x00,0x1C,0x22,0x41,0x00, # (
    0x00,0x41,0x22,0x1C,0x00, # )
    0x2A,0x1C,0x7F,0x1C,0x2A, # *
    0x08,0x08,0x3E,0x08,0x08, # +
    0x00,0x80,0x70,0x30,0x00, # ,
    0x08,0x08,0x08,0x08,0x08, # -
    0x00,0x00,0x60,0x60,0x00, # .
    0x20,0x10,0x08,0x04,0x02, # /
    0x3E,0x51,0x49,0x45,0x3E, # 0
    0x00,0x42,0x7F,0x40,0x00, # 1
    0x72,0x49,0x49,0x49,0x46, # 2
    0x21,0x41,0x49,0x4D,0x33, # 3
    0x18,0x14,0x12,0x7F,0x10, # 4
    0x27,0x45,0x45,0x45,0x39, # 5
    0x3C,0x4A,0x49,0x49,0x31, # 6
    0x41,0x21,0x11,0x09,0x07, # 7
    0x36,0x49,0x49,0x49,0x36, # 8
    0x46,0x49,0x49,0x29,0x1E, # 9
    0x00,0x00,0x14,0x00,0x00, # :
    0x00,0x40,0x34,0x00,0x00, # ;
    0x00,0x08,0x14,0x22,0x41, # <
    0x14,0x14,0x14,0x14,0x14, # =
    0x00,0x41,0x22,0x14,0x08, # >
    0x02,0x01,0x59,0x09,0x06, # ?
    0x3E,0x41,0x5D,0x59,0x4E, # @
    0x7C,0x12,0x11,0x12,0x7C, # A
    0x7F,0x49,0x49,0x49,0x36, # B
    0x3E,0x41,0x41,0x41,0x22, # C
    0x7F,0x41,0x41,0x41,0x3E, # D
    0x7F,0x49,0x49,0x49,0x41, # E
    0x7F,0x09,0x09,0x09,0x01, # F
    0x3E,0x41,0x41,0x51,0x73, # G
    0x7F,0x08,0x08,0x08,0x7F, # H
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
    0x02,0x04,0x08,0x10,0x20, # backslash
    0x00,0x41,0x41,0x41,0x7F, # ]
    0x04,0x02,0x01,0x02,0x04, # ^
    0x40,0x40,0x40,0x40,0x40, # _
    0x00,0x03,0x07,0x08,0x00, # `
    0x20,0x54,0x54,0x78,0x40, # a
    0x7F,0x28,0x44,0x44,0x38, # b
    0x38,0x44,0x44,0x44,0x28, # c
    0x38,0x44,0x44,0x28,0x7F, # d
    0x38,0x54,0x54,0x54,0x18, # e
    0x00,0x08,0x7E,0x09,0x02, # f
    0x18,0xA4,0xA4,0x9C,0x78, # g
    0x7F,0x08,0x04,0x04,0x78, # h
    0x00,0x44,0x7D,0x40,0x00, # i
    0x20,0x40,0x40,0x3D,0x00, # j
    0x7F,0x10,0x28,0x44,0x00, # k
    0x00,0x41,0x7F,0x40,0x00, # l
    0x7C,0x04,0x78,0x04,0x78, # m
    0x7C,0x08,0x04,0x04,0x78, # n
    0x38,0x44,0x44,0x44,0x38, # o
    0xFC,0x18,0x24,0x24,0x18, # p
    0x18,0x24,0x24,0x18,0xFC, # q
    0x7C,0x08,0x04,0x04,0x08, # r
    0x48,0x54,0x54,0x54,0x24, # s
    0x04,0x04,0x3F,0x44,0x24, # t
    0x3C,0x40,0x40,0x20,0x7C, # u
    0x1C,0x20,0x40,0x20,0x1C, # v
    0x3C,0x40,0x30,0x40,0x3C, # w
    0x44,0x28,0x10,0x28,0x44, # x
    0x4C,0x90,0x90,0x90,0x7C, # y
    0x44,0x64,0x54,0x4C,0x44, # z
    0x00,0x08,0x36,0x41,0x00, # {
    0x00,0x00,0x77,0x00,0x00, # |
    0x00,0x41,0x36,0x08,0x00, # }
    0x02,0x01,0x02,0x04,0x02, # ~
])


# =============================================================================
# CHAOS MODULATION ENGINE
# =============================================================================
class ChaosEngine:
    """Generates chaotic signals via logistic map for VCO modulation."""

    def __init__(self):
        self.x_gps = 0.1 + (time.ticks_us() % 800) / 1000.0   # Random seed
        self.x_wifi = 0.4 + (time.ticks_us() % 500) / 1000.0
        # Lorenz state
        self.lx = 1.0
        self.ly = 1.0
        self.lz = 1.0
        self.algorithm = 0  # 0=logistic, 1=lorenz

    def step_logistic(self):
        """Advance logistic map for both channels."""
        self.x_gps = CHAOS_R * self.x_gps * (1.0 - self.x_gps)
        self.x_wifi = CHAOS_R * self.x_wifi * (1.0 - self.x_wifi)
        # Prevent convergence to fixed points
        if self.x_gps < 0.01 or self.x_gps > 0.99:
            self.x_gps = 0.3 + (time.ticks_us() % 400) / 1000.0
        if self.x_wifi < 0.01 or self.x_wifi > 0.99:
            self.x_wifi = 0.6 + (time.ticks_us() % 300) / 1000.0

    def step_lorenz(self):
        """Advance Lorenz attractor, map x->GPS, y->WiFi."""
        dx = LORENZ_SIGMA * (self.ly - self.lx) * LORENZ_DT
        dy = (self.lx * (LORENZ_RHO - self.lz) - self.ly) * LORENZ_DT
        dz = (self.lx * self.ly - LORENZ_BETA * self.lz) * LORENZ_DT
        self.lx += dx
        self.ly += dy
        self.lz += dz
        # Normalize Lorenz output to 0-1 range (typical range: x=-20..20)
        self.x_gps = max(0.0, min(1.0, (self.lx + 25.0) / 50.0))
        self.x_wifi = max(0.0, min(1.0, (self.ly + 30.0) / 60.0))

    def step(self):
        """Advance one step using selected algorithm."""
        if self.algorithm == 0:
            self.step_logistic()
        else:
            self.step_lorenz()

    def gps_dac_value(self):
        """Get DAC value for GPS VCO TUNE pin."""
        val = int(GPS_DAC_CENTER + (self.x_gps - 0.5) * 2.0 * GPS_DAC_SWING)
        return max(0, min(255, val))

    def wifi_dac_value(self):
        """Get DAC value for WiFi VCO TUNE pin."""
        val = int(WIFI_DAC_CENTER + (self.x_wifi - 0.5) * 2.0 * WIFI_DAC_SWING)
        return max(0, min(255, val))

    def toggle_algorithm(self):
        self.algorithm = 1 - self.algorithm
        return "LORENZ" if self.algorithm else "LOGISTIC"


# =============================================================================
# HARDWARE SETUP
# =============================================================================
# DAC outputs for VCO tuning
dac_gps = machine.DAC(machine.Pin(PIN_GPS_TUNE))
dac_wifi = machine.DAC(machine.Pin(PIN_WIFI_TUNE))
dac_gps.write(0)
dac_wifi.write(0)

# ADC inputs
adc_therm = machine.ADC(machine.Pin(PIN_THERM_ADC))
adc_therm.atten(machine.ADC.ATTN_11DB)
adc_therm.width(machine.ADC.WIDTH_12BIT)

adc_batt = machine.ADC(machine.Pin(PIN_BATT_ADC))
adc_batt.atten(machine.ADC.ATTN_11DB)
adc_batt.width(machine.ADC.WIDTH_12BIT)

# Digital I/O
bias_ok_pin = machine.Pin(PIN_BIAS_OK, machine.Pin.IN)
bias_en = machine.Pin(PIN_BIAS_EN, machine.Pin.OUT, value=0)
relay_ctrl = machine.Pin(PIN_RELAY_CTRL, machine.Pin.OUT, value=0)
btn_a = machine.Pin(PIN_BTN_A, machine.Pin.IN, machine.Pin.PULL_UP)
btn_b = machine.Pin(PIN_BTN_B, machine.Pin.IN, machine.Pin.PULL_UP)

try:
    buzzer = machine.PWM(machine.Pin(PIN_BUZZER), freq=2000, duty=0)
except Exception:
    buzzer = None

# Watchdog
wdt = machine.WDT(timeout=10000)

# Chaos engine
chaos = ChaosEngine()


# =============================================================================
# SENSOR FUNCTIONS
# =============================================================================
def read_temperature():
    total = 0
    for _ in range(ADC_SAMPLES):
        total += adc_therm.read()
        time.sleep_us(100)
    avg = total // ADC_SAMPLES
    if avg <= 0 or avg >= ADC_MAX:
        return None
    resistance = SERIES_RESISTOR * avg / (ADC_MAX - avg)
    if resistance <= 0:
        return None
    steinhart = math.log(resistance / NOMINAL_RESISTANCE) / B_COEFFICIENT
    steinhart += 1.0 / NOMINAL_TEMP_K
    return (1.0 / steinhart) - 273.15


def read_battery_voltage():
    total = 0
    for _ in range(ADC_SAMPLES):
        total += adc_batt.read()
        time.sleep_us(100)
    avg = total // ADC_SAMPLES
    if avg <= 0:
        return 0.0
    return (avg / ADC_MAX) * V_REF * BATT_DIVIDER_RATIO


def read_bias_ok():
    return bias_ok_pin.value() == 1


# =============================================================================
# POWER SEQUENCING
# =============================================================================
def enable_pa():
    """Enable PA with GaN-safe bias sequencing.
    Gate bias (-5V) MUST be present before drain voltage.
    """
    bias_en.value(1)
    time.sleep_ms(SEQUENCER_DELAY_MS)
    # Verify BIAS_OK from LM393 comparator
    if not read_bias_ok():
        # Wait additional time for charge pump to stabilize
        time.sleep_ms(50)
        if not read_bias_ok():
            print("!! BIAS_OK not confirmed — aborting PA enable")
            bias_en.value(0)
            return False
    relay_ctrl.value(1)
    return True


def disable_pa():
    """Disable PA: drain OFF first, then gate bias removed."""
    relay_ctrl.value(0)
    time.sleep_ms(SEQUENCER_DELAY_MS)
    bias_en.value(0)


def beep(freq=2000, duration_ms=100):
    if buzzer:
        buzzer.freq(freq)
        buzzer.duty(512)
        time.sleep_ms(duration_ms)
        buzzer.duty(0)


# =============================================================================
# DISPLAY MANAGER
# =============================================================================
class Display:
    def __init__(self):
        self.lcd = None
        try:
            self.lcd = ST7789()
            self.lcd.fill(DARK_BG)
        except Exception as e:
            print("Display init failed: {}".format(e))
        self._last_mode = -1
        self._last_temp = -999
        self._last_batt = -999
        self._last_status = ""

    def splash(self):
        if not self.lcd:
            return
        self.lcd.fill(DARK_BG)
        self.lcd.text("jamRF", 30, 20, ORANGE, 3)
        self.lcd.text("v2.0", 42, 50, WHITE, 2)
        self.lcd.text("Chaos Modulated", 6, 90, CYAN, 1)
        self.lcd.text("RF Platform", 21, 105, CYAN, 1)
        self.lcd.text("A:Mode  B:Algo", 9, 200, WHITE, 1)
        self.lcd.text("Initializing...", 9, 220, YELLOW, 1)

    def update(self, mode, temp, batt, armed, algo, fault_msg=None):
        if not self.lcd:
            return
        # Only redraw changed sections
        if mode != self._last_mode:
            self.lcd.fill_rect(0, 0, 135, 30, DARK_BG)
            mode_colors = [WHITE, GREEN, BLUE, ORANGE]
            self.lcd.text("MODE:", 5, 5, WHITE, 2)
            self.lcd.text(MODE_NAMES[mode], 70, 5, mode_colors[mode], 2)
            self._last_mode = mode

        # Temperature bar
        t_int = int(temp) if temp else -999
        if t_int != self._last_temp:
            self.lcd.fill_rect(0, 35, 135, 45, DARK_BG)
            t_str = "{:.1f}C".format(temp) if temp else "FAULT"
            t_color = RED if (temp and temp >= SHUTDOWN_TEMP_C) else \
                      YELLOW if (temp and temp >= RECOVERY_TEMP_C) else GREEN
            self.lcd.text("TEMP", 5, 38, WHITE, 1)
            self.lcd.text(t_str, 40, 38, t_color, 2)
            # Progress bar
            if temp:
                bar_w = max(0, min(125, int((temp / 100.0) * 125)))
                self.lcd.fill_rect(5, 60, 125, 8, BLACK)
                self.lcd.fill_rect(5, 60, bar_w, 8, t_color)
            self._last_temp = t_int

        # Battery
        b_int = int(batt * 10) if batt else -999
        if b_int != self._last_batt:
            self.lcd.fill_rect(0, 75, 135, 30, DARK_BG)
            b_str = "{:.1f}V".format(batt) if batt else "?"
            b_color = RED if batt < UNDERVOLT_CUTOFF_V else \
                      YELLOW if batt < UNDERVOLT_RECOVER_V else GREEN
            self.lcd.text("BATT", 5, 78, WHITE, 1)
            self.lcd.text(b_str, 40, 78, b_color, 2)
            # Percentage bar (12.0V=0%, 16.8V=100%)
            pct = max(0, min(100, int((batt - 12.0) / 4.8 * 100)))
            self.lcd.fill_rect(5, 98, 125, 8, BLACK)
            self.lcd.fill_rect(5, 98, int(pct * 1.25), 8, b_color)
            self._last_batt = b_int

        # Status area
        status = "ARMED" if armed else "SAFE"
        if fault_msg:
            status = fault_msg
        if status != self._last_status:
            self.lcd.fill_rect(0, 115, 135, 50, DARK_BG)
            s_color = GREEN if armed else RED if fault_msg else WHITE
            self.lcd.text(status, 5, 120, s_color, 2)
            algo_name = "LORENZ" if algo else "LOGISTIC"
            self.lcd.text("Algo:" + algo_name, 5, 145, CYAN, 1)
            self._last_status = status

        # Footer
        self.lcd.fill_rect(0, 220, 135, 20, DARK_BG)
        self.lcd.text("A:Mode  B:Algo", 9, 225, WHITE, 1)
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

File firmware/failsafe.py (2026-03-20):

"""
jamRF-v2 Thermal Failsafe System
================================
Target: M5StickC Plus 2 (ESP32-PICO-V3-02)
Runtime: MicroPython

Monitors NTC thermistor on heatsink via voltage divider.
Shuts down amplifiers at 85C, re-enables after cooldown to 80C.
Two-stage power sequencing for GaN PA safety.

Wiring (matches jamrf-v2 schematic):
  +3V3 -> R_TH (10k) -> ADC (G36) -> NTC (10k @ 25C) -> GND
  +14V8 -> R_BATT1 (100k) -> ADC (G0) -> R_BATT2 (22k) -> GND
  G33 -> BIAS_EN (LM2776 charge pump enable, generates -5V gate bias)
  G32 -> RELAY_CTRL (Q3 gate -> Q2 P-FET WiFi PA power switch)
  G25/DAC -> GPS_TUNE (VCO1 chaos modulation)
  G26/DAC -> WIFI_TUNE (VCO2 chaos modulation)

Power sequencing (GaN PA depletion-mode safety):
  Enable:  BIAS_EN HIGH (charge pump on, -5V gate bias)
           -> wait for BIAS_OK (LM393 confirms -5V present)
           -> RELAY_CTRL HIGH (PA drain power on)
  Disable: RELAY_CTRL LOW (PA drain power off first)
           -> wait 15ms (POSCAP bleed)
           -> BIAS_EN LOW (charge pump off, gate bias removed)

Safety behavior:
  - System starts OFF (both outputs LOW)
  - 3-second startup delay before enabling
  - Continuous 1Hz temperature AND battery voltage monitoring
  - Immediate shutdown on overtemperature (85C) or undervoltage (<13V)
  - 5C hysteresis on temperature, 0.5V hysteresis on voltage
  - Sensor fault detection (open/short circuit NTC)
  - Watchdog timer resets system if firmware hangs
"""

import machine
import time
import math

# =============================================================
# PIN CONFIGURATION (matches jamrf-v2 schematic)
# =============================================================
THERMISTOR_PIN = 36   # G36 - ADC1_CH0 input from NTC voltage divider (always available)
BATTERY_PIN = 0       # G0  - ADC input from battery voltage divider
BIAS_EN_PIN = 33      # G33 - Output: LM2776 charge pump enable (generates -5V gate bias)
RELAY_CTRL_PIN = 32   # G32 - Output: Q3 gate -> Q2 P-FET WiFi PA drain switch
BUZZER_PIN = 2        # Internal buzzer (M5StickC built-in)
SEQUENCER_DELAY_MS = 15  # Delay between bias enable and PA drain enable (ms)

# =============================================================
# SAFETY THRESHOLDS
# =============================================================
SHUTDOWN_TEMP_C = 85.0     # Amplifiers OFF above this
RECOVERY_TEMP_C = 80.0     # Amplifiers ON below this (hysteresis)
SENSOR_FAULT_LOW = -20.0   # Below this = sensor open circuit
SENSOR_FAULT_HIGH = 150.0  # Above this = sensor short circuit
UNDERVOLT_CUTOFF_V = 13.0  # ZVE-3W-83+ minimum supply voltage
UNDERVOLT_RECOVER_V = 13.5 # Re-enable after battery recovers
STARTUP_DELAY_S = 3        # Delay before first enable
SAMPLE_INTERVAL_S = 1      # Temperature polling rate
ADC_SAMPLES = 16           # Number of ADC readings to average

# =============================================================
# THERMISTOR PARAMETERS (Vishay NTCS0805E3103FMT)
# =============================================================
B_COEFFICIENT = 3950       # Beta value (K)
NOMINAL_RESISTANCE = 10000 # Ohms at nominal temperature
NOMINAL_TEMP_K = 298.15    # 25C in Kelvin
SERIES_RESISTOR = 10000    # Fixed series resistor (ohms)
ADC_MAX = 4095             # ESP32 12-bit ADC
V_REF = 3.3                # ADC reference voltage

# =============================================================
# BATTERY VOLTAGE DIVIDER (R_BATT1=100k / R_BATT2=22k)
# V_adc = V_batt * R_BATT2 / (R_BATT1 + R_BATT2)
# V_batt = V_adc * (R_BATT1 + R_BATT2) / R_BATT2
# =============================================================
R_BATT1 = 100000          # High-side divider resistor (ohms)
R_BATT2 = 22000           # Low-side divider resistor (ohms)
BATT_DIVIDER_RATIO = (R_BATT1 + R_BATT2) / R_BATT2  # ~5.545

# =============================================================
# HARDWARE INITIALIZATION
# =============================================================
adc = machine.ADC(machine.Pin(THERMISTOR_PIN))
adc.atten(machine.ADC.ATTN_11DB)  # Full range 0-3.3V
adc.width(machine.ADC.WIDTH_12BIT)

batt_adc = machine.ADC(machine.Pin(BATTERY_PIN))
batt_adc.atten(machine.ADC.ATTN_11DB)
batt_adc.width(machine.ADC.WIDTH_12BIT)

bias_en = machine.Pin(BIAS_EN_PIN, machine.Pin.OUT)
bias_en.value(0)  # Start with charge pump OFF

relay_ctrl = machine.Pin(RELAY_CTRL_PIN, machine.Pin.OUT)
relay_ctrl.value(0)  # Start with PA drain switches OFF

# Watchdog timer - resets if firmware hangs for >10 seconds
wdt = machine.WDT(timeout=10000)

# =============================================================
# STATE TRACKING
# =============================================================
system_armed = False
fault_count = 0
undervolt_active = False
MAX_CONSECUTIVE_FAULTS = 5


def read_adc_averaged():
    """Read ADC with oversampling to reduce noise."""
    total = 0
    for _ in range(ADC_SAMPLES):
        total += adc.read()
        time.sleep_ms(1)
    return total // ADC_SAMPLES


def adc_to_temperature(adc_val):
    """
    Convert ADC reading to temperature using Steinhart-Hart
    (simplified Beta equation).

    Circuit: 3V3 -> R_TH (10k fixed) -> ADC_NODE -> NTC (10k @ 25C) -> GND
    V_adc = V_ref * R_ntc / (R_series + R_ntc)
    R_ntc = R_series * adc_val / (ADC_MAX - adc_val)
    """
    if adc_val <= 0 or adc_val >= ADC_MAX:
        return None  # Sensor fault

    resistance = SERIES_RESISTOR * adc_val / (ADC_MAX - adc_val)

    if resistance <= 0:
        return None

    # Steinhart-Hart (Beta equation)
    steinhart = math.log(resistance / NOMINAL_RESISTANCE)
    steinhart /= B_COEFFICIENT
    steinhart += 1.0 / NOMINAL_TEMP_K
    temp_k = 1.0 / steinhart

    return temp_k - 273.15


def read_battery_voltage():
    """Read battery voltage via resistive divider on G36."""
    total = 0
    for _ in range(ADC_SAMPLES):
        total += batt_adc.read()
        time.sleep_ms(1)
    avg = total // ADC_SAMPLES
    if avg <= 0:
        return 0.0
    v_adc = (avg / ADC_MAX) * V_REF
    return v_adc * BATT_DIVIDER_RATIO


def set_system_state(enabled):
    """Enable/disable PA power with asymmetric GaN bias sequencing.

    Enable:  charge pump ON first (-5V gate bias) -> wait -> PA drain ON
    Disable: PA drain OFF first -> wait for POSCAP bleed -> charge pump OFF
    This prevents depletion-mode GaN Idss runaway.
    """
    global system_armed
    system_armed = enabled
    if enabled:
        # Enable: gate bias BEFORE drain voltage
        bias_en.value(1)
        time.sleep_ms(SEQUENCER_DELAY_MS)
        relay_ctrl.value(1)
    else:
        # Disable: drain voltage OFF BEFORE gate bias removed
        relay_ctrl.value(0)
        time.sleep_ms(SEQUENCER_DELAY_MS)
        bias_en.value(0)


def alarm_pulse(count=3):
    """Pulse relay_ctrl LED as visual alarm."""
    for _ in range(count):
        relay_ctrl.value(1)
        time.sleep_ms(200)
        relay_ctrl.value(0)
        time.sleep_ms(200)
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

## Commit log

2026-03-20 Initial release: JamRF v2 dual-band chaos-modulated RF transmitter
    Hardware design (KiCad 9.0):
    - Hierarchical schematic: baseband, frontend GPS/WiFi, power, control
    - GPS L1 (1.575 GHz): MAX2751 VCO -> TGA2215-SM GaN PA
    - WiFi/ISM (2.4 GHz): MAX2750 VCO -> ZVE-3W-83+ PA
    - 4S LiPo power with buck, LDO, charge pump, P-FET switched PA rails
    - LM393 GaN bias sequencing, NTC thermal monitoring
    Firmware:
    - MicroPython thermal failsafe for M5StickC Plus2 (ESP32)
    - Overtemperature/undervoltage shutdown with hysteresis
    - Asymmetric GaN PA power sequencing
    Licensed under CERN-OHL-P v2.
    [BOM.csv, baseband.kicad_sch, control.kicad_sch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]
2026-03-21 jamrf-v2: Add U3V70F15 WiFi PA regulator, FR408HR stackup, full firmware, custom footprints
    - Add U3V70F15 buck-boost converter to limit WiFi PA supply to 15V (fixes ZVE-3W-83+ overvoltage)
    - Update PCB stackup to Isola FR408HR (Er=3.65, tan d=0.0095) with corrected 0.40mm 50-ohm traces
    - Add full operational firmware (main.py): chaos modulation engine, ST7789 display, mode control
    - Add 6 custom footprints: M5StickC, Pololu D24V10F5/U3V70F15, Mini-Circuits, Wurth shield, isolator
    - Add fp-lib-table and sym-lib-table for custom libraries
    - Update README with logo, badges, TIIUAE disclaimer, corrected specs
    - Update LICENSE with proper attribution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
    [baseband.kicad_sch, control.kicad_sch, frontend_gps.kicad_sch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]
2026-03-21 Annotate all component references and update CLAUDE.md
    - All component references annotated (U1-U10, R1-R17, C1-C19, Q1-Q4, etc.)
    - Fix CLAUDE.md: correct jamrf-v4 description (dual-band, not WiFi-only)
    - Update CLAUDE.md: file paths match main branch structure, add firmware docs
    - Remove resolved known issues (annotation, footprint library)
    [baseband.kicad_sch, control.kicad_sch, frontend_gps.kicad_sch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]
2026-03-23 Add component buy list with Turkish/Turkey-shipping supplier links
    Creates hardware/BUYLIST.md with purchase links for all BOM components.
    Prefers Turkish domestic suppliers (Direnc.net, Robotistan.com), then
    EU/global distributors that ship to Turkey (Mouser TR, TME, DigiKey).
    Includes 2+ source links per component and notes on hard-to-source
    RF parts (TGA2215-SM GaN PA, Mini-Circuits isolators, MAX2750/51 VCOs).
    https://claude.ai/code/session_01PsHcWMcNLyvZ592tamkcZC
2026-04-23 upload renders
    the renders taken from kicad and visualizers respectively
